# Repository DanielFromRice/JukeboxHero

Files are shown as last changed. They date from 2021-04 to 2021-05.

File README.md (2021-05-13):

# JukeboxHero
ELEC327 Final Project

Team CLARG:
Mac Carr
Kevin Lata
Michael Angino
Daniel Rothfusz
Elise Gibney

In this project, we are using MSP430G2553 microcontrollers to play a 
version of Guitar Hero.

There are 3 distinct PCBs:
	1. Controller Board
	2. Speaker Boards
	3. Break Beam Boards

1. Controller Board:
This board functions as a central controller module. It facilitates song 
selection, loading data from the SD card, managing a timing module, and 
commmunicating data to the other modules. The SD card uses SPI communication
implementing the PetitFs library (http://elm-chan.org/fsw/ff/00index_p.html)
Song selection is done using 3 buttons, implementing up, down, and select.
Support for a display module is intended for future development.

2. Speaker Boards:
These boards basically consist of a speaker and an MSP430. They wait to 
receive a signal from the controller over I2C, and when they do, they 
change their frequency with the new data they have received.

3. Break Beam Boards: 
This board facilitates communication to the DotStar LED strips and 
to the breakbeam sensors. This board is preloaded with break beam song data
once a song has been selected, and then proceeds to advance the lights and 
track a user's score as it receives notice from the central controller.

Overall, the game should function similarly to Guitar Hero. Lights descend 
along the DotStar strips, signaling which beam break sensor the player should
trip. The order of these loosely correspond to a song that is playing, which
produces multiple tones over a collection of piezzo buzzers. 

To run:
Once boards are wired up with the appropriate hardware, open 3 projects in 
Code Composer Studio. Load all the code from ControllerBoardCode to the 
Controller board, load code from the Break_Beam folder to the Break Beam 
Board, and load the code from SpeakerBoardCode to each speaker board, 
ensuring that each one gets a different I2C address.

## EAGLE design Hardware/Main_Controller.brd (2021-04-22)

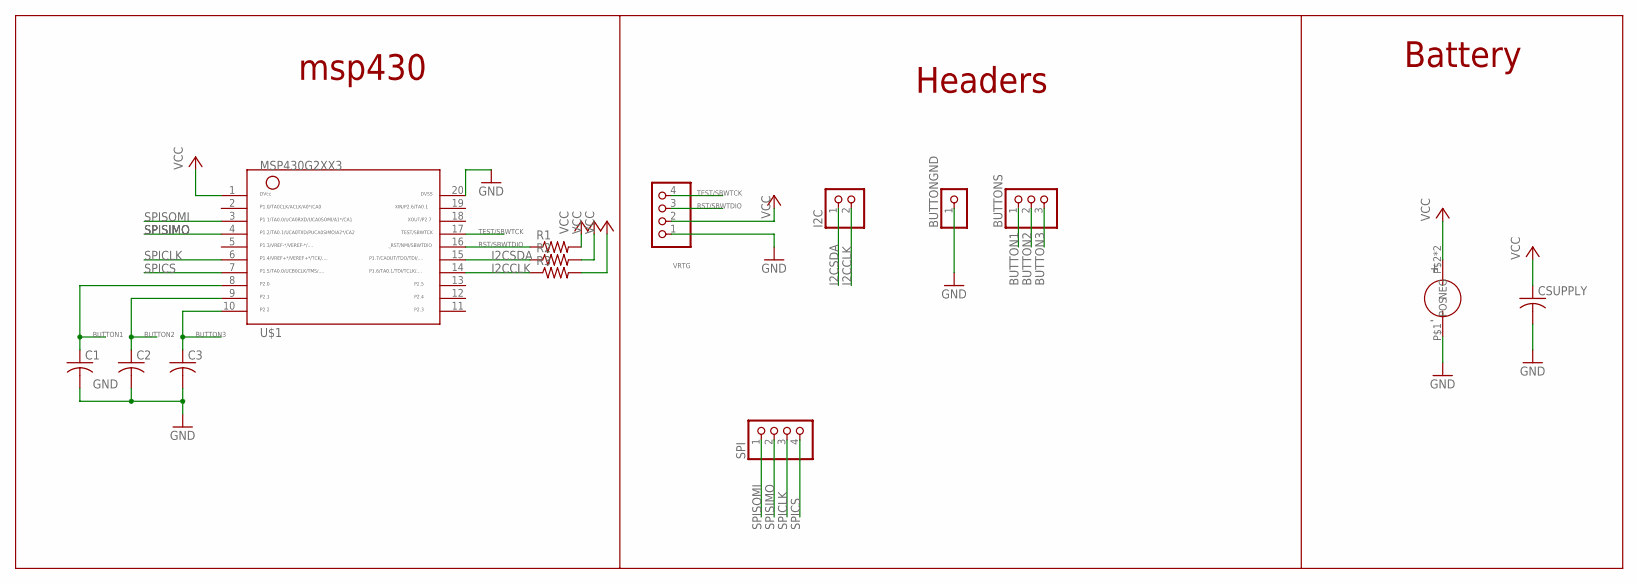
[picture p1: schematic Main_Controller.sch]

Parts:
BUTTONGND: PINHD-1X1; 1X01
BUTTONS: PINHD-1X3; 1X03
C1, C2, C3: C-USC1206; C1206
CSUPPLY: C-USC1206; C1206
I2C: PINHD-1X2; 1X02
R1, R2, R3: R-US_R1206; R1206
SPI: PINHD-1X4; 1X04
U$1: MSP430G2XX3TSSOP; PW20
U$2: 3002BATTERY
VRTG: PINHD-1X4; 1X04

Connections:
BUTTON1: BUTTONS.1, C1.1, U$1.8
BUTTON2: BUTTONS.2, C2.1, U$1.9
BUTTON3: BUTTONS.3, C3.1, U$1.10
GND: BUTTONGND.1, C1.2, C2.2, C3.2, CSUPPLY.2, U$1.20, U$2.P$1 (NEG), VRTG.1
I2CCLK: I2C.2, R3.1, U$1.14
I2CSDA: I2C.1, R2.1, U$1.15
RST/SBWTDIO: R1.1, U$1.16, VRTG.3
SPICLK: SPI.3, U$1.6
SPICS: SPI.4, U$1.7
SPISIMO: SPI.2, U$1.4
SPISOMI: SPI.1, U$1.3
TEST/SBWTCK: U$1.17, VRTG.4
VCC: CSUPPLY.1, R1.2, R2.2, R3.2, U$1.1, U$2.P$2 (POS), U$2.P$3 (POS), VRTG.2

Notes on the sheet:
msp430
Headers
Battery

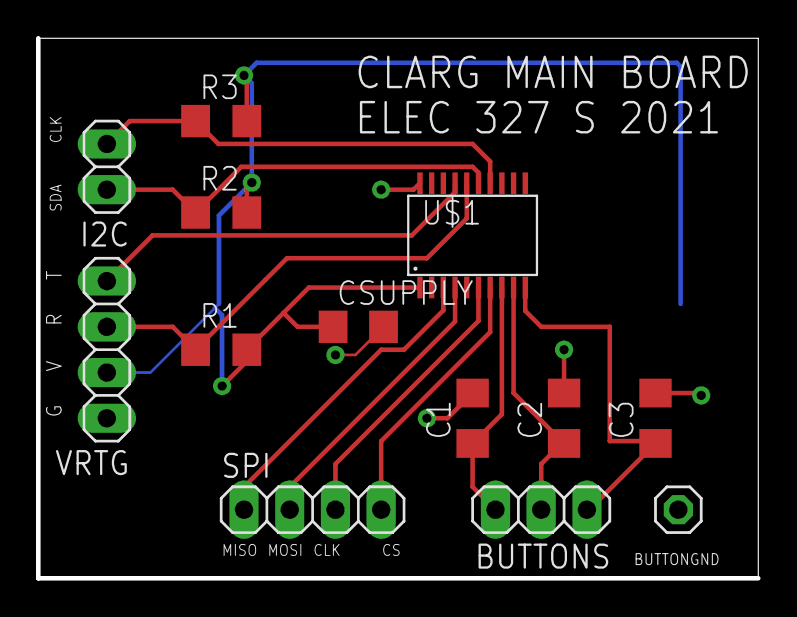
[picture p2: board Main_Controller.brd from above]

Board: 2 copper layers, 40.0 x 30.0 mm, 14 parts (1 on the bottom side), 13 nets.

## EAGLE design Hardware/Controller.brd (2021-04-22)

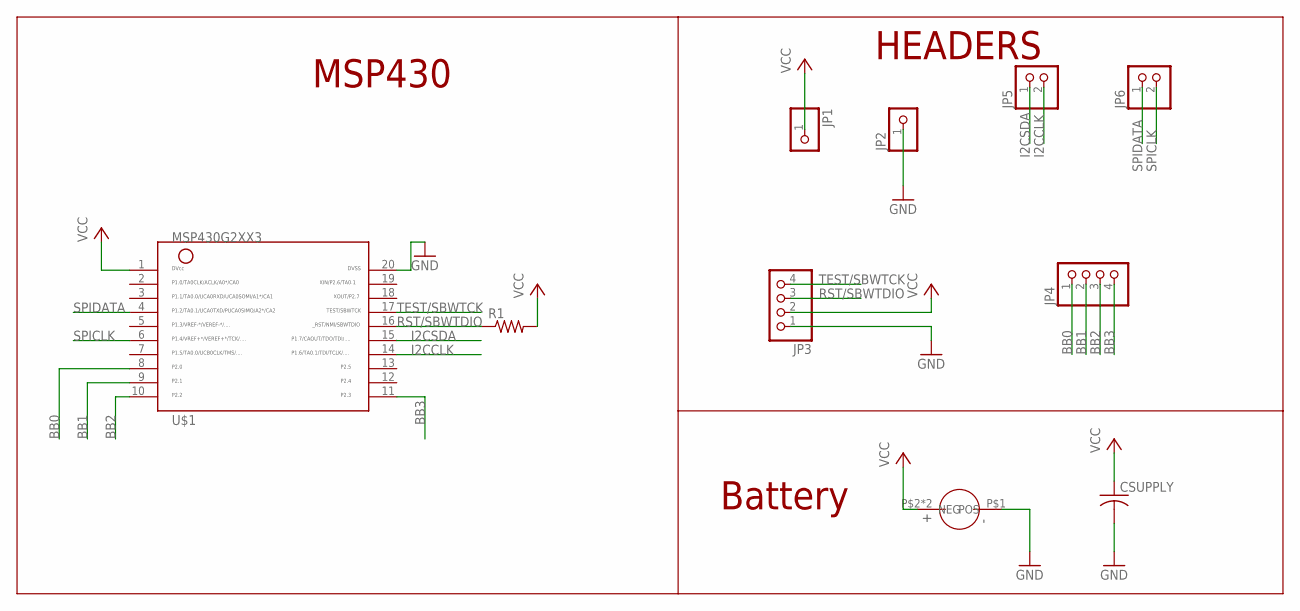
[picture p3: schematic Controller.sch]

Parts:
CSUPPLY: C-USC1206; C1206
JP1, JP2: PINHD-1X1; 1X01
JP3, JP4: PINHD-1X4; 1X04
JP5, JP6: PINHD-1X2; 1X02
R1: R-US_R1206; R1206
U$1: MSP430G2XX3TSSOP; PW20
U$2: 3002BATTERY

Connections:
BB0: JP4.1, U$1.8
BB1: JP4.2, U$1.9
BB2: JP4.3, U$1.10
BB3: JP4.4, U$1.11
GND: CSUPPLY.2, JP2.1, JP3.1, U$1.20, U$2.P$1 (NEG)
I2CCLK: JP5.2, U$1.14
I2CSDA: JP5.1, U$1.15
RST/SBWTDIO: JP3.3, R1.1, U$1.16
SPICLK: JP6.2, U$1.6
SPIDATA: JP6.1, U$1.4
TEST/SBWTCK: JP3.4, U$1.17
VCC: CSUPPLY.1, JP1.1, JP3.2, R1.2, U$1.1, U$2.P$2 (POS), U$2.P$3 (POS)

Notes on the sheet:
MSP430
HEADERS
Battery

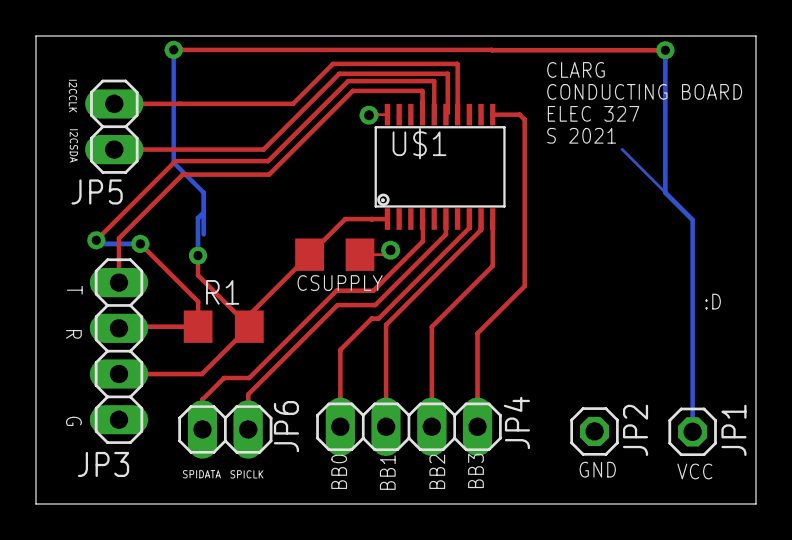
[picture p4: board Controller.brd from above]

Board: 2 copper layers, 40.0 x 26.0 mm, 10 parts (1 on the bottom side), 12 nets.

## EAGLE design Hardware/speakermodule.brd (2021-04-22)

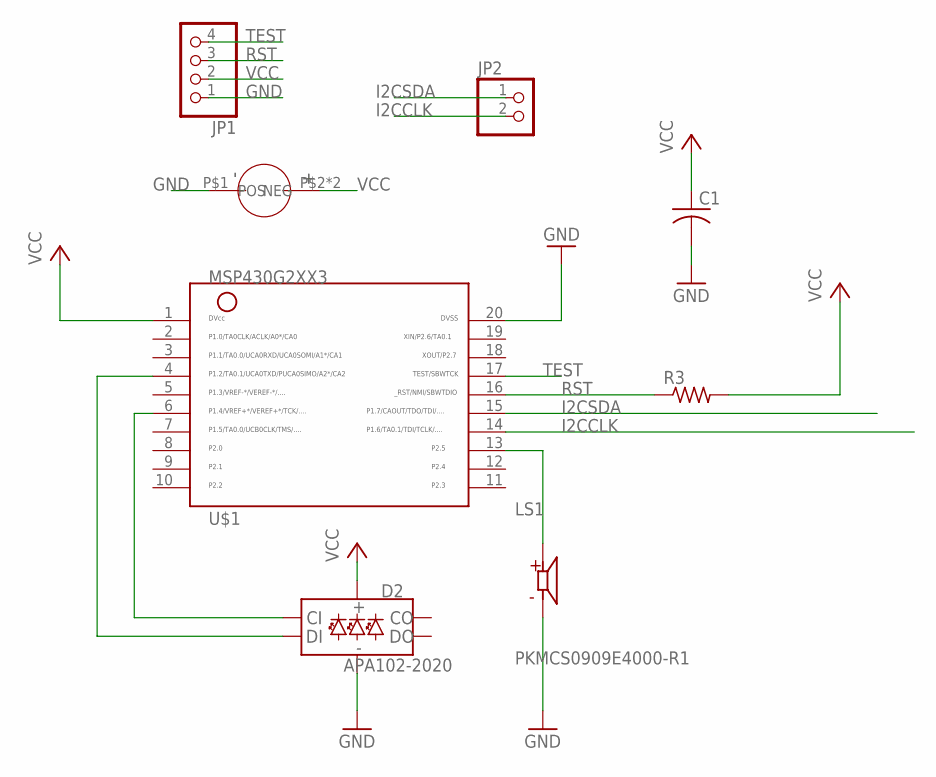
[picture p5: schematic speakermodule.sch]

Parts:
C1: C-USC1206; C1206
D2: APA102-2020
JP1: PINHD-1X4; 1X04
JP2: PINHD-1X2; 1X02
LS1: PKMCS0909E4000-R1; SPKR_PKMCS0909E4000-R1
R3: R-US_R1206; R1206
U$1: MSP430G2XX3TSSOP; PW20
U$3: 3002BATTERY

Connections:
GND: C1.2, D2.GND, JP1.1, LS1.2 (N), U$1.20, U$3.P$1 (NEG)
I2CCLK: JP2.2, U$1.14
I2CSDA: JP2.1, U$1.15
unnamed: LS1.1, U$1.13
unnamed: D2.CKI (CI), U$1.6
unnamed: D2.SDI (DI), U$1.4
RST: JP1.3, R3.1, U$1.16
TEST: JP1.4, U$1.17
VCC: C1.1, D2.VDD (VCC), JP1.2, R3.2, U$1.1, U$3.P$2 (POS), U$3.P$3 (POS)

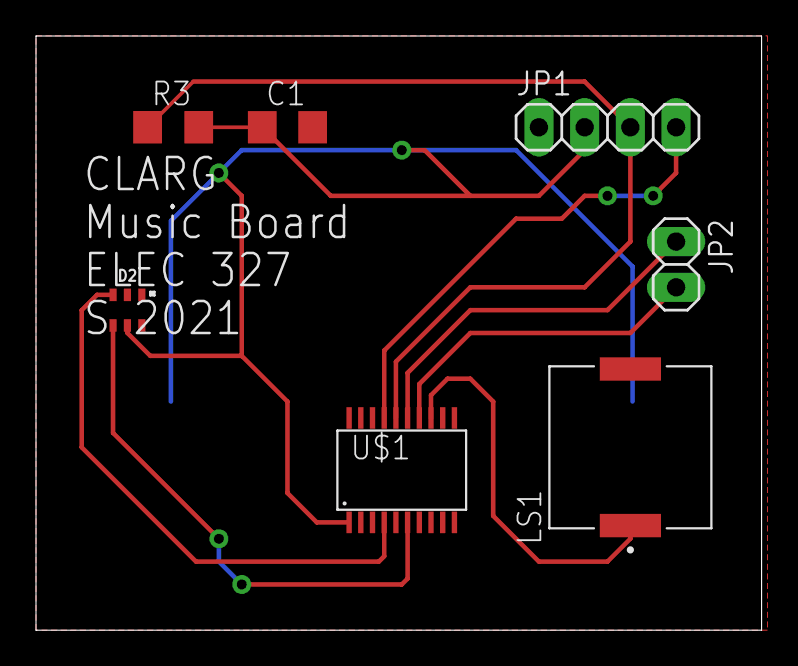
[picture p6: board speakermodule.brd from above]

Board: 2 copper layers, 40.3 x 33.0 mm, 8 parts (1 on the bottom side), 9 nets.

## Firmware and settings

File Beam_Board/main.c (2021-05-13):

/**
 * main.c
 *
 * Main file for controlling the break beam feedback board for team CLARG's
 * Jukebox Hero project.
 *
 * Author:
 *      Kevin Lata
 */

#include <msp430.h>
#include <stdint.h>
#include "rgb_interface.h"
#include "display_change.h"

void init_wdt(void);
void init_buttons(void);
int receive_bytes(void* pointer_to_memory);

uint8_t beam_values[154]; // Should hold all of the beam pattern data and have extra room just in case
uint8_t beam_values_size; // Value letting us know how long the beam pattern array is

unsigned char *PRxData; // Pointers and variables used in receiving data from the main board
unsigned char RXByteCtr;

int main_reciept_flag = 0; // flag for checking if you've gotten a value from the main board
int sequence_iter = 0; // general use iterating variable
int playertics = 0; // ticking time for evaluating a player's performance
uint8_t current_button = 0; // variable to check against to see what button should be pressed, should be between 0-3
int thresh = 20000; //threshold amount for how many tics until the player loses/gets no points
int listenout = 0; // outcome variable for listening to a player's interaction
int current_check; // Variable for checking if the wrong beam was broken (equivalent to wrong button press)
int playerscore = 0; // value containing the player's score
int main_flag = 0; // i2c interrupt flag for the middle of the game
int player_flag = 0; // player interrupt flag (player has broken a beam)
int new_iter = 0; // additional iterating variable
uint8_t real_one = 0; //variable for changing the LED display to the correct iteration
int has_scored = 0; // variable to keep track if the player has scored already or not
uint8_t p2reg = 0; // variable to be used in checking if the correct beam was broken

void init_wdt(void){ // initiates watch dog timer
    BCSCTL3 |= LFXT1S_2;     // ACLK = VLO
    WDTCTL = WDT_ADLY_16;    // WDT 16ms (~43.3ms since clk 12khz), ACLK, interval timer
    IE1 |= WDTIE;            // Enable WDT interrupt
}

void init_buttons(void) { // initiates port 2 register values for button interrupts/input
    P2DIR &= ~(BIT0 + BIT1 + BIT2 + BIT3); // set to input
    P2REN = BIT0 + BIT1 + BIT2 + BIT3; // enable pullup/down resistors
    P2OUT = BIT0 + BIT1 + BIT2 + BIT3; // set resistors to pull up
    P2IES = BIT0 + BIT1 + BIT2 + BIT3; // listen for high to low transitions
    P2IFG &=  ~(BIT0 + BIT1 + BIT2 + BIT3); // clear any pending interrupts
    P2IE = BIT0 + BIT1 + BIT2 + BIT3; // enable interrupts for these pins
}

int receive_bytes(void* pointer_to_memory){
    PRxData = (unsigned char *)pointer_to_memory;    // Start of RX buffer
       RXByteCtr = 0;                          // Clear RX byte count
       __bis_SR_register(LPM0_bits + GIE); // Enter LPM0 w/ interrupts
       __no_operation();                // Remain in LPM0 until master finishes TX
       return RXByteCtr;

}

int main(void)
{

    WDTCTL = WDTPW + WDTHOLD;                 // Stop WDT
    P1SEL |= BIT6 + BIT7;                     // Assign I2C pins to USCI_B0
    P1SEL2|= BIT6 + BIT7;                     // Assign I2C pins to USCI_B0
    UCB0CTL1 |= UCSWRST;                      // Enable SW reset
    UCB0CTL0 = UCMODE_3 + UCSYNC;             // I2C Slave, synchronous mode
    UCB0I2COA = 0x50;                         // Own Address is 048h
    UCB0CTL1 &= ~UCSWRST;                     // Clear SW reset, resume operation
    UCB0I2CIE |= UCSTPIE + UCSTTIE;           // Enable STT and STP interrupt
    IE2 |= UCB0RXIE;                          // Enable RX interrupt

    enum state_enum{Start, ListenForInt, SendToBoard} state;
    state = Start;
    //The following sets up watchdog timer related values
    WDTCTL = WDTPW | WDTHOLD;   // stop watchdog timer
    DCOCTL = 0;                 // Select lowest DCOx and MODx settings
    BCSCTL1 = CALBC1_16MHZ;     // Set range
    DCOCTL = CALDCO_16MHZ;      // Set DCO step + modulation */
    BCSCTL3 |= LFXT1S_2;        // ACLK = VLO

    uint8_t status = 0; // variable used for receiving signals from the main board during the "gaming" state (ListenForInt)

    int Button_LED_map[] = {0, BIT0,BIT1,0,BIT2,0,0,0,BIT3};
    uint8_t current_bit; //hex value that represents dec number 0-3

    init_buttons(); // initialization functions
    rgb_init_spi();

    while(1){
        if(state == Start){ // In this state the board will receive the beam array pattern from the main board and store it
            receive_bytes(&beam_values_size); // It receives the size of the data to be received first
            for (sequence_iter = 0;sequence_iter < beam_values_size;sequence_iter++){
                receive_bytes(&beam_values[sequence_iter]); // It gets it one byte at a time which is why this for loop is necessary
            }
            for (new_iter = sequence_iter+1;new_iter <sequence_iter+4;new_iter++){
                beam_values[new_iter] = 0; // this pads the beam_values array after it recieved all of the relevant data with 0 values
            }
            new_iter = 0;
            change_display(beam_values[0]); // These three lines load the first three display updates onto the strip display
            change_display(beam_values[1]); // Such that by the time the game starts (the board listens to player interrupts)
            change_display(beam_values[2]); // The bottom most row has an LED on (since display updates go from the top down)
            sequence_iter = 3; // Values set to whatever necessary to move onto the nect state
            main_flag = 0;
            player_flag = 0;
            state = ListenForInt;
//            init_wdt();
        }
        else if (state==ListenForInt){
            while(listenout == 0){ // use another one to exit
//                __bis_SR_register(LPM0_bits + GIE);
                receive_bytes(&status); // Goes to sleep until an interrupt takes place
                if (main_flag == 1){ // main board i2c run interrupt
                    if (sequence_iter > beam_values_size-5){ // In this case, the song has finished playing
                        listenout = 99; // listenout = 99 is end of song flag
                        sequence_iter = 0; // resets value since it will exit this state soon
                    }
                    else if (sequence_iter < beam_values_size){ // In this case, the song is in the middle of playing and display should update
                        current_button = beam_values[sequence_iter-3]; // The button corresponding to the bottom LED was at the top 3 iters ago
                        real_one = beam_values[sequence_iter]; // Current value that determines how to update the top row of the display
                        current_bit = Button_LED_map[current_button]; // essentially passes it to a lookup table to get its associated value
                        //current_check = ((BIT0 + BIT1 + BIT2 + BIT3) & (~current_bit));
                        change_display(real_one); // changes the display according to the correct value
                        playertics = 0; // resets player timer since the display has just changed
                        sequence_iter = sequence_iter + 1; // updates where in the array we currently are
                        has_scored = 0; // flag for designating that the display has been updated
                    }
                    main_flag = 0; // interrupt flag for getting update from main board is cleared
                }
                if (player_flag == 1){ // player run interrupt was triggered
                    if ((playertics < thresh)&&((~p2reg & current_bit) == current_bit)){ // correct beam was broken and player didnt time out
                        playerscore = playerscore+1; //  player's score increases by 1
                        write_correct(); // LEDs display that the player got this note correctly/got a point, bottom row lights up green
                    }
                    else if (playertics < thresh) {
                        playerscore = playerscore-1; // player broke the wrong beam
                        write_incorrect(); // LEDs display that the player got this note incorrectly/lost a point, bottom row lights up red
                    }
                    player_flag = 0; // clears associated interrupt flag
                    has_scored =1; // designates that after a display update, the player responded, either correctly or incorrectly
                }
                playertics = playertics+1; // player timer increases
            }
            playertics = 0; // Upon exiting this state, reset certain values
            listenout = 0;
            sequence_iter = 0;
            state = SendToBoard;
        }
        else if (state == SendToBoard){ // This state displays on the LED strips the player's performance
            //send playerscore to the board, not sure how this happens
            write_score(playerscore, beam_values_size); // Depending on what fraction of the total notes the player got correct
//            playerscore = 0; // they may receive 0, 1, 2, 3, or 4 rows worth of LEDs be on
//            state = Start;
        }
        __bis_SR_register(LPM0_bits + GIE); // little bit of a time gap between states
    }


    return 0;
}


// Watchdog Timer interrupt service routine
#if defined(__TI_COMPILER_VERSION__) || defined(__IAR_SYSTEMS_ICC__)
#pragma vector=WDT_VECTOR
__interrupt void watchdog_timer(void)
#elif defined(__GNUC__)
void __attribute__ ((interrupt(WDT_VECTOR))) watchdog_timer (void)
#else
#error Compiler not supported!
#endif
{
    //timer_wakeup_flag = 1;
    __bic_SR_register_on_exit(LPM0_bits); // exit LPM3 when returning to program (clear LPM3 bits)
}

// Watchdog Timer interrupt service routine
#if defined(__TI_COMPILER_VERSION__) || defined(__IAR_SYSTEMS_ICC__)
#pragma vector=PORT2_VECTOR
__interrupt void button(void)
#elif defined(__GNUC__)
void __attribute__ ((interrupt(PORT2_VECTOR))) button (void)
#else
#error Compiler not supported!
#endif
{
    if(has_scored ==0){ // PLayer broke a beam after the display has been updated
        player_flag = 1;
    }
    p2reg = P2IN;
    P2IFG &= ~(BIT0 + BIT1 + BIT2 + BIT3);
    __bic_SR_register_on_exit(LPM0_bits); // exit LPM3 when returning to program (clear LPM3 bits)
}

#if defined(__TI_COMPILER_VERSION__) || defined(__IAR_SYSTEMS_ICC__)
#pragma vector = USCIAB0TX_VECTOR
__interrupt void USCIAB0TX_ISR(void)
#elif defined(__GNUC__)
void __attribute__ ((interrupt(USCIAB0TX_VECTOR))) USCIAB0TX_ISR (void)
#else
#error Compiler not supported!
#endif
{

  *PRxData = UCB0RXBUF;                   // Move RX data to address PRxData
  RXByteCtr++;                              // Increment RX byte count
}

//------------------------------------------------------------------------------
// The USCI_B0 state ISR is used to wake up the CPU from LPM0 in order to
// process the received data in the main program. LPM0 is only exit in case
// of a (re-)start or stop condition when actual data was received.
//------------------------------------------------------------------------------
#if defined(__TI_COMPILER_VERSION__) || defined(__IAR_SYSTEMS_ICC__)
#pragma vector = USCIAB0RX_VECTOR
__interrupt void USCIAB0RX_ISR(void)
#elif defined(__GNUC__)
void __attribute__ ((interrupt(USCIAB0RX_VECTOR))) USCIAB0RX_ISR (void)
#else
#error Compiler not supported!
#endif
{
  main_flag =1; // signal from main board has been received
  UCB0STAT &= ~(UCSTPIFG + UCSTTIFG);       // Clear interrupt flags
  if (RXByteCtr)                            // Check RX byte counter
    __bic_SR_register_on_exit(LPM0_bits);      // Exit LPM0 if data was
}

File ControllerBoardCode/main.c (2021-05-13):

/*
 *  main.c
 *
 *  Author:
 *      Daniel Rothfusz, Michael Angino, Mac Carr, Kevin Lata, Elise Gibney
 *
 *  Manages the game loop for the main module for Jukebox Hero project.
 *
 *  Selects song, then reads data from the SD card. Loads the preload array
 *  of beam data to the beam module, then dynamically loads and broadcasts
 *  song data to the speaker modules.
 *
 *  SD modules adapted from: https://gist.github.com/RickKimball/2407353
 */

#include <msp430.h>
#include <stdint.h>
#include <stdbool.h>

#include "SPI.h"
#include "diskio.h"
#include "pff.h"
#include "mmc.h"
#include "sd_funcs.h"
#include "buttons.h"

void init_wdt(void);
void i2c_init(void);
void i2c_send_bytes(int address, void * data, int len_of_array);

const char* const paths[] = {"AllStar.bin", "LidaRose.bin"};
#define MAXSONG  2

// Button variables
extern bool bsel_edge, bup_edge, bdown_edge;

// Gamestate management
enum gamestate{song_select, loop, endgame} state;
struct packet pkt;
uint8_t data_byte, num_pkts, total_pkts;
uint16_t ticks, duration;

// Display and buttons
uint16_t display_val;

// I2C stuff
unsigned char *PTxData;                 // Pointer to TX data
unsigned char TXByteCtr;

#define BB_ADDR     0x50               // Break beam board address

#define SOP_ADDR    0x48               // Speaker board addresses
#define ALT_ADDR    0x49
#define TEN_ADDR    0x4A
#define BAS_ADDR    0x4B

#define NO_CHANGE   256                // Hardcoded value in binary data


void init_wdt(void) {
    BCSCTL3 |= LFXT1S_2;      // ACLK = VLO
    WDTCTL = WDT_ADLY_1_9;    // WDT 1.9ms (~43.3ms since clk actually 12khz), ACLK, interval timer
    IE1 |= WDTIE;             // Enable WDT interrupt
}

void i2c_init(void) {
    P1SEL |= BIT6 + BIT7;                     // Assign I2C pins to USCI_B0
    P1SEL2|= BIT6 + BIT7;                     // Assign I2C pins to USCI_B0
    UCB0CTL1 |= UCSWRST;                      // Enable SW reset
    UCB0CTL0 = UCMST + UCMODE_3 + UCSYNC;     // I2C Master, synchronous mode
    UCB0CTL1 = UCSSEL_2 + UCSWRST;            // Use SMCLK, keep SW reset
    UCB0BR0 = 12;                             // fSCL = SMCLK/12 = ~100kHz
    UCB0BR1 = 0;
    UCB0I2CSA = 0x48;                         // Slave Address is 048h
    UCB0CTL1 &= ~UCSWRST;                     // Clear SW reset, resume operation
    IE2 |= UCB0TXIE;                          // Enable TX interrupt
}


void i2c_send_bytes(int address, void * data, int len_of_array) {
   UCB0I2CSA = address;
   PTxData = (unsigned char *)data;      // TX array start address
   TXByteCtr = len_of_array;             // Load TX byte counter
   while (UCB0CTL1 & UCTXSTP);             // Ensure stop condition got sent
   UCB0CTL1 |= UCTR + UCTXSTT;             // I2C TX, start condition
   __bis_SR_register(LPM0_bits + GIE);        // Enter LPM0 w/ interrupts
   // Remain in LPM0 until all data is TX'd
}


int main(void) {

    // INITIALIZATION
    WDTCTL = WDTPW + WDTHOLD; // Stop WDT

    DCOCTL = 0; // Run at 1 MHz
    BCSCTL1 = CALBC1_1MHZ;
    DCOCTL = CALDCO_1MHZ;
    __delay_cycles(0xffff); // delay for power up and stabilization

    button_init();
    button_ready();
    i2c_init();
    sd_init();

    init_wdt();

    display_val = 1;

    // GAME LOOP
    while (1) {
        switch(state) {
        case song_select: // Initial state, selects a song and preloads data
            // Start read on button press
            button_update();
            if (bup_edge) {
                if (display_val == MAXSONG)
                    display_val = 1;
                else
                    display_val += 1;
                bup_edge = false;
            }
            if (bdown_edge) {
                if (display_val == 1)
                    display_val = MAXSONG;
                else
                    display_val -= 1;
                bdown_edge = false;
            }
            if (bsel_edge) {
                // Load song and enter next state (songs are 1 indexed)
                if (sd_open(paths[display_val-1]) != FR_OK) {
                    while(1);
                }

                IE1 &= ~WDTIE;             // Disable WDT interrupt

                // Read beam array:
                uint8_t i;
                sd_read_byte(&total_pkts);
                i2c_send_bytes(BB_ADDR, &total_pkts, 1);
                for (i = 0; i < total_pkts; i++) {
                    sd_read_byte(&data_byte); // Sends one byte at a time to avoid storing lots of data
                    i2c_send_bytes(BB_ADDR, &data_byte, 1);
                }

                sd_read_byte(&total_pkts); // Read number of packets
                // Load first packet
                if (sd_read_packet(&pkt) != FR_OK) {
                    while(1);
                }
                num_pkts = 1;               // Lists number of packets read in

                state = loop;               // Init loop state
                ticks = 1;
                duration = 0;

                IE1 |= WDTIE;               // Enable WDT interrupt
            }
            break;
        case loop: // Main game state, dynamically loads packet data and broadcasts
            ticks += 1;
            if (ticks >= duration) {
                IE1 &= ~WDTIE;             // Disable WDT interrupt

                // Send current packet data
//                if (pkt.note_s != NO_CHANGE)
//                    i2c_send_bytes(SOP_ADDR, &(pkt.note_s), 2);
                if (pkt.note_a != NO_CHANGE)
                    i2c_send_bytes(ALT_ADDR, &(pkt.note_a), 2);
//                if (pkt.note_t != NO_CHANGE)
//                    i2c_send_bytes(TEN_ADDR, &(pkt.note_t), 2);
                if (pkt.note_b != NO_CHANGE)
                    i2c_send_bytes(BAS_ADDR, &(pkt.note_b), 2);
                if (pkt.beam_state != 0)
                    i2c_send_bytes(BB_ADDR, &(pkt.beam_state), 1);

                ticks = 0;
                duration = pkt.duration;

                IE1 |= WDTIE;             // Enable WDT interrupt

                if (num_pkts >= total_pkts) {
                    state = endgame;     // Switch to end of game when all packets are read
                    ticks = 0;
                    break;
                }
                if (sd_read_packet(&pkt) != FR_OK) {
                    while(1);
                }
                num_pkts += 1;
            }
            break;
        case endgame:
            IE1 &= ~WDTIE;             // Disable WDT interrupt

            // Write "off" to each board
            pkt.note_s = 0;
            pkt.note_a = 0;
            pkt.note_t = 0;
            pkt.note_b = 0;
            int zero=0;
//            i2c_send_bytes(SOP_ADDR, &(pkt.note_s), 2);
            i2c_send_bytes(ALT_ADDR, &zero, 2);
//            i2c_send_bytes(TEN_ADDR, &(pkt.note_t), 2);
            i2c_send_bytes(BAS_ADDR, &zero, 2);

        }
        __bis_SR_register(LPM0_bits + GIE);
    }

    return 0;
}
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

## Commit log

2021-04-19 Added initial files and controller board scematics
    [Controller.brd, Controller.sch]
2021-04-19 Added Speaker Eagle Files
    [Speaker.brd, Speaker.sch]
2021-04-21 Main Board rough draft finished
    [Main_Controller.brd, Main_Controller.sch]
2021-04-21 main board draft 2
    [Main_Controller.sch]
2021-04-21 controller board draft 1
    [Controller.brd, Controller.sch]
2021-04-21 added capacitor to main board
    [Main_Controller.brd, Main_Controller.sch]
2021-04-21 Renamed Battery Library
2021-04-21 Resized Main Board Name
    [Main_Controller.brd]
2021-04-21 resized controller board name
    [Controller.brd]
2021-04-21 removed extra i2c resistors
    [Controller.brd, Controller.sch]
2021-04-22 Speaker Module
    [Speaker.brd, Speaker.sch, speakermodule.brd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]
2021-04-22 cam jobs and battery updates for controller and speaker boards
    [Controller.brd, speakermodule.brd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]
2021-04-22 main board battery issue changes and cam job
    [Main_Controller.brd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]
2021-05-10 Added speaker board code, need to update addresses
2021-05-10 Controller Board Code v1
2021-05-10 Fixed build on Controller Code
    [main.c, mmc.c]
2021-05-11 Fixed ports for speakerboard
    [speakerboard.c]
2021-05-11 Updated Controller board to use buttons
2021-05-11 added inital beam board code
2021-05-11 Lida Rose Ready
    [LidaRoseBeams.csv, LidaRoseNotes.csv]
2021-05-11 updated beam board code
2021-05-12 Reorganization and README
    [AllStarBeams.csv, AllStarNotes.csv, BugleBeams.csv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]
2021-05-13 Controller board comments

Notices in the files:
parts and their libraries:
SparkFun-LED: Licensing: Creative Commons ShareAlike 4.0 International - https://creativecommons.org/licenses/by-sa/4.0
